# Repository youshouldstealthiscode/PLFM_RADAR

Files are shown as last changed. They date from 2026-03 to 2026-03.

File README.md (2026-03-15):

# AERIS-10: Open Source Pulse Linear Frequency Modulated Phased Array Radar




)


AERIS-10 Radar System

AERIS-10 is an open-source, low-cost 10.5 GHz phased array radar system featuring Pulse Linear Frequency Modulated (LFM) modulation. Available in two versions (3km and 20km range), it's designed for researchers, drone developers, and serious SDR enthusiasts who want to explore and experiment with phased array radar technology.

AERIS-10 Radar System

## 📡 Overview

The AERIS-10 project aims to democratize radar technology by providing a fully open-source, modular, and hackable radar system. Whether you're a university researcher, a drone startup, or an advanced maker, AERIS-10 offers a platform for experimenting with beamforming, pulse compression, Doppler processing, and target tracking.

## 🔬 Key Features

- **Open Source Hardware & Software** - Complete schematics, PCB layouts, firmware, and software available
- **Dual Version Availability**:
  - **AERIS-10N (Nexus)**: 3km range with 8x16 patch antenna array
  - **AERIS-10E (Extended)**: 20km range with 32x16 dielectric-filled slotted waveguide array
- **Full Electronic Beam Steering** - ±45° electronic steering in elevation and azimuth
- **Advanced Signal Processing** - On-board FPGA handles pulse compression, Doppler FFT, MTI, and CFAR
- **Python GUI** - User-friendly interface with map integration
- **GPS/IMU Integration** - Real-time position and attitude correction
- **Modular Design** - Separate power management, frequency synthesis, and RF boards

## 🏗️ System Architecture

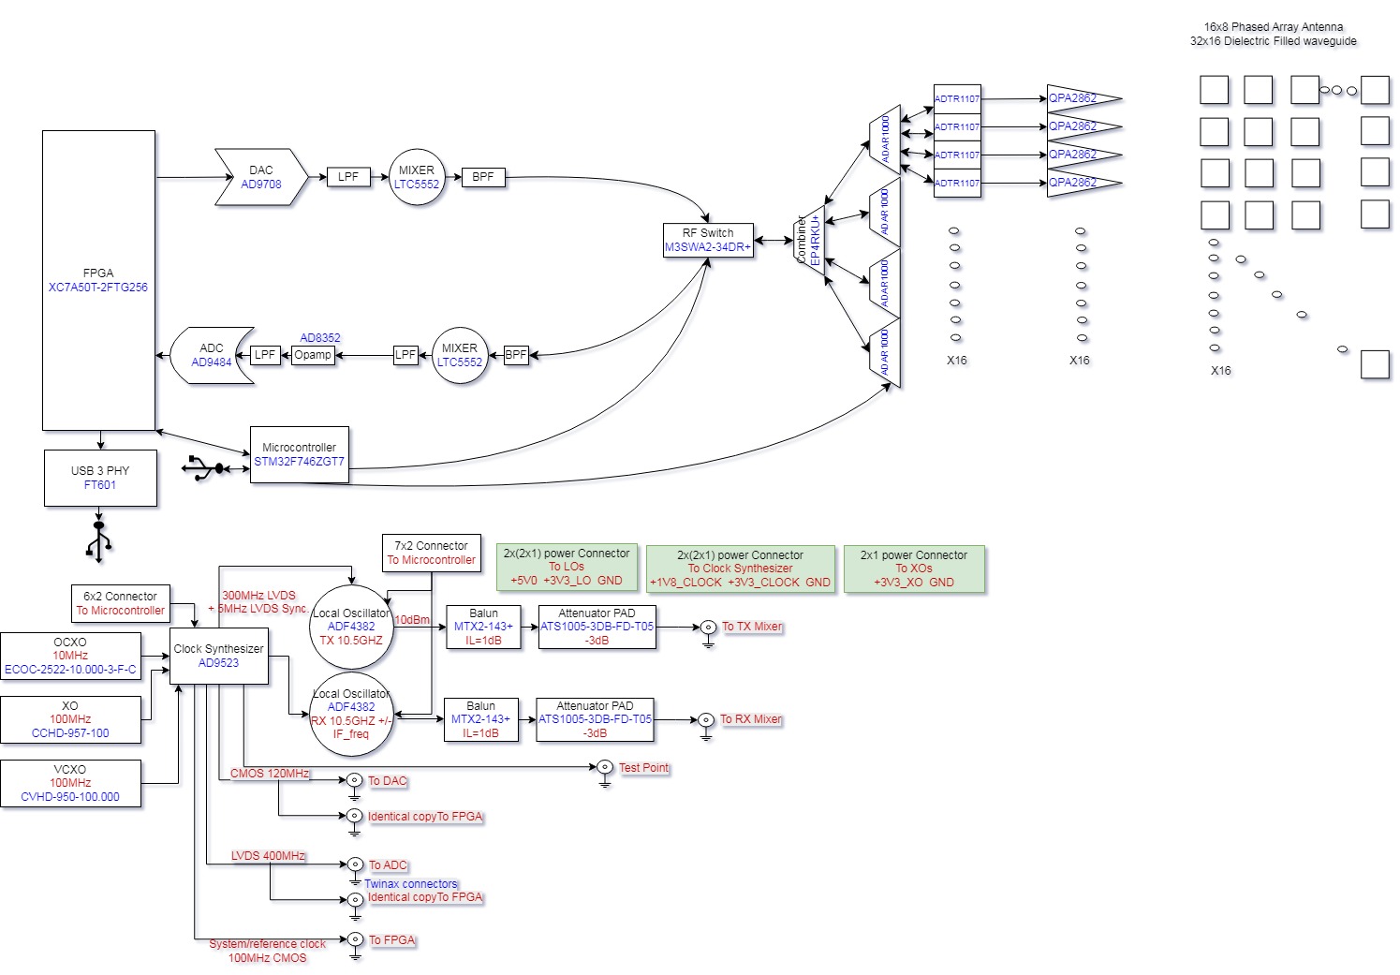
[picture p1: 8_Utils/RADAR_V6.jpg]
AERIS-10 Radar System


### Hardware Components

The AERIS-10 main sub-systems are:

- **Power Management Board** - Supplies all necessary voltage levels to the electronics components with proper filtering and sequencing (sequencing ensured by the microcontroller)

- **Frequency Synthesizer Board** - Uses a high-performance Low Jitter Clock Generator (AD9523-1) that supplies phase-aligned clock references for:
  - RX and TX Frequency Synthesizers (ADF4382)
  - DAC
  - ADC
  - FPGA

- **Main Board** containing:
  - **DAC** - Generates the RADAR Chirps
  - **2x Microwave Mixers (LT5552)** - For up-conversion and IF-down-conversion
  - **4x 4-Channel Phase Shifters (ADAR1000)** - For RX and TX chain beamforming
  - **16x Front End Chips (ADTR1107)** - Used for both Low Noise Amplifying (RX) and Power Amplifying (TX) stages
  - **XC7A100T FPGA** - Handles RADAR Signal Processing:
    - PLFM Chirps generation via the DAC
    - Raw ADC data read
    - Automatic Gain Control (AGC)
    - I/Q Baseband Down-Conversion
    - Decimation
    - Filtering
    - Forward FFT
    - Pulse Compression
    - Doppler, MTI and CFAR processing
    - USB Interface
  - **STM32F746xx Microcontroller** - Used for:
    - Power-up and power-down sequencing (see Power Management Excel File)
    - FPGA communication
    - Setup and Interface with:
      - Clock Generator (AD9523-1)
      - 2x Frequency Synthesizers (ADF4382)
      - 4x 4-Channel Phase Shifters (ADAR1000) for RADAR pulse sequencing
      - 2x ADS7830 ADCs (on Power Amplifier Boards) for Idq measurement
      - 2x DAC5578 (on Power Amplifier Boards) for Vg control
      - GPS module for GUI map centering
      - GY-85 IMU for pitch/roll correction of target coordinates
      - BMP180 Barometer
      - Stepper Motor
      - 8x ADS7830 Temperature Sensors for cooling fan control
      - RF switches

- **16x Power Amplifier Boards** - Used only for AERIS-10E version, featuring 10Watt QPA2962 GaN amplifier for extended range

- **Antenna Arrays**:
  - **AERIS-10N (Nexus)** - 8x16 patch antenna array
  - **AERIS-10X (Extended)** - 32x16 dielectric-filled slotted waveguide antenna array

- **Miscellaneous Components**:
  - Slip-Ring
  - Stepper Motor and drivers
  - Cooling Fans
  - Enclosure) 

### Processing Pipeline

1. **Waveform Generation** - DAC creates LFM chirps
2. **Up/Down Conversion** - LT5552 mixers handle frequency translation
3. **Beam Steering** - ADAR1000 phase shifters control 16 elements
4. **Signal Processing (FPGA)**:
   - Raw ADC data capture
   - I/Q baseband down-conversion
   - Decimation & filtering (CIC/FIR)
   - Pulse compression
   - Doppler FFT processing
   - MTI & CFAR detection
5. **System Management (STM32)**:
   - Power sequencing
   - Peripheral configuration
   - GPS/IMU integration
   - Stepper motor control
6. **Visualization (Python GUI)**:
   - Real-time target plotting
   - Map integration
   - Radar control interface

AERIS-10 Radar System

## 📊 Technical Specifications

| Parameter | AERIS-10N (Nexus) | AERIS-10X (Extended) |
|---|---|---|
| **Frequency** | 10.5 GHz | 10.5 GHz |
| **Max Range** | 3 km | 20 km |
| **Antenna** | 8x16 Patch Array | 32x16 Slotted Waveguide |
| **Beam Steering** | Electronic (±45°) | Electronic (±45°) |
| **Mechanical Scan** | 360° (stepper motor) | 360° (stepper motor) |
| **Output Power** | ~1Wx16 | 10Wx16 (GaN amplifier) |
| **Processing** | FPGA + STM32 | FPGA + STM32 |

## 🚀 Getting Started

### Prerequisites

- Basic understanding of radar principles
- Experience with PCB assembly (for hardware build)
- Python 3.8+ for the GUI software
- FPGA development tools (Vivado) for signal processing modifications

### Hardware Assembly

1. **Order PCBs**: All Gerber files are available in `/4_Schematics and Boards Layout`
2. **Source Components**: Bill of materials (BOM) in `/4_Schematics and Boards Layout/4_7_Production Files`
3. **Assembly**: Follow the assembly guide in `/10_docs/assembly_guide.md`
4. **Antenna**: Choose appropriate array for your version
5. **Enclosure**: 3D printable files in `/10_docs/Hardware/Enclosure`

## 📜 License

This project is open-source but uses **different licenses for hardware and software** to ensure proper legal coverage.

### Hardware Documentation
The hardware design files—including:
- Schematics and PCB layouts (in `/4_Schematics and Boards Layout`)
- Bill of Materials (BOM) files
- Gerber files and manufacturing outputs
- Mechanical drawings and enclosure designs

are licensed under the **CERN Open Hardware Licence Version 2 – Permissive (CERN-OHL-P)** .

This is a hardware-specific license that:
- ✅ Clearly defines "Hardware," "Documentation," and "Products"
- ✅ Includes explicit patent protection for contributors and users
- ✅ Provides stronger liability limitations (important for high-power RF)
- ✅ Aligns with professional open-hardware standards (CERN, OSHWA)

You may use, modify, and sell products based on these designs, provided you:
- Maintain the original copyright notices
- Distribute any modified designs under the same license
- Make your modifications available in Source format

### Software and Firmware
The software components—including:
- FPGA code (VHDL/Verilog in `/9_Firmware`)
- Microcontroller firmware (STM32)
- Python GUI and utilities

remain under the **MIT License** for maximum flexibility.

### Full License Texts
- The complete CERN-OHL-P license text is in the `LICENSE` file
- MIT license terms apply to software where not otherwise specified

### Why This Change?
Originally, the entire project used the MIT license. The community (special thanks to gmaynez!) pointed out that MIT lacks legal protections needed for physical hardware. The switch to CERN-OHL-P ensures the project is properly protected while maintaining the same permissive spirit.

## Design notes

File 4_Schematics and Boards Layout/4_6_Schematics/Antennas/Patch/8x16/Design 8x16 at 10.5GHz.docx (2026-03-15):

Design 8x16 at 10.5 GHz

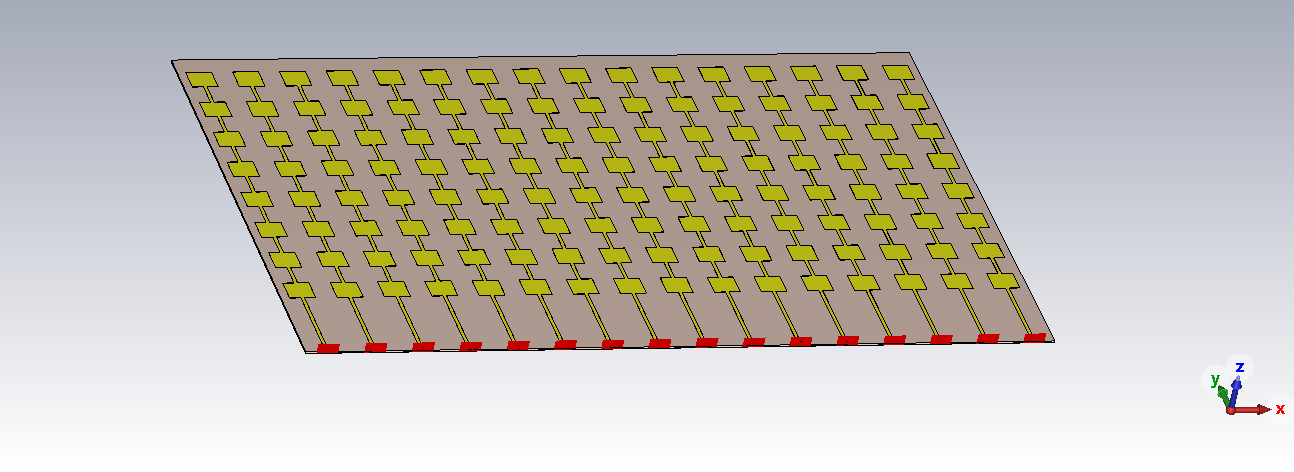
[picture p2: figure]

Working Frequency 10.5 GHz

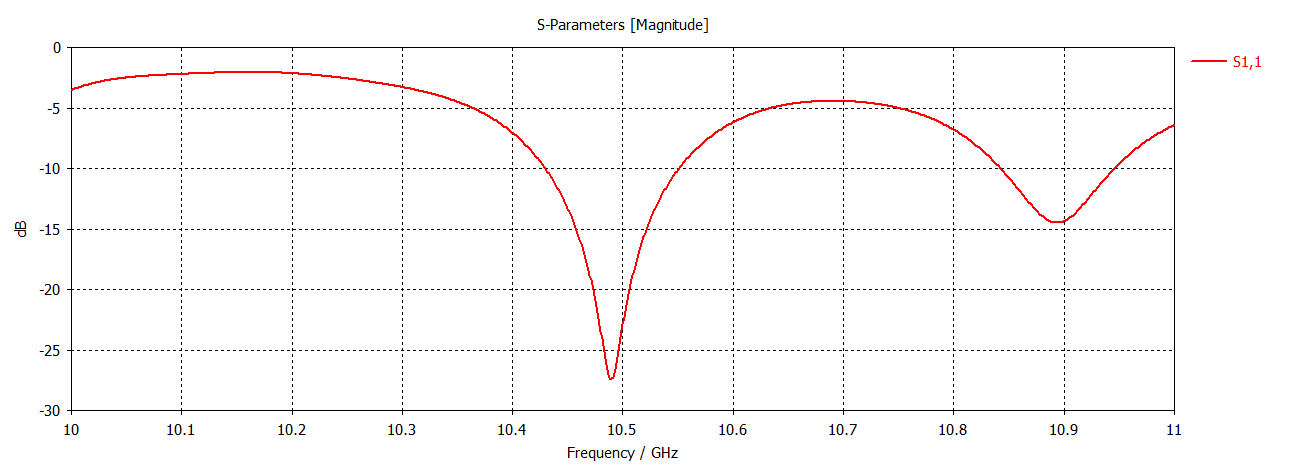
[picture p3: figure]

Gain 24.3 dBi

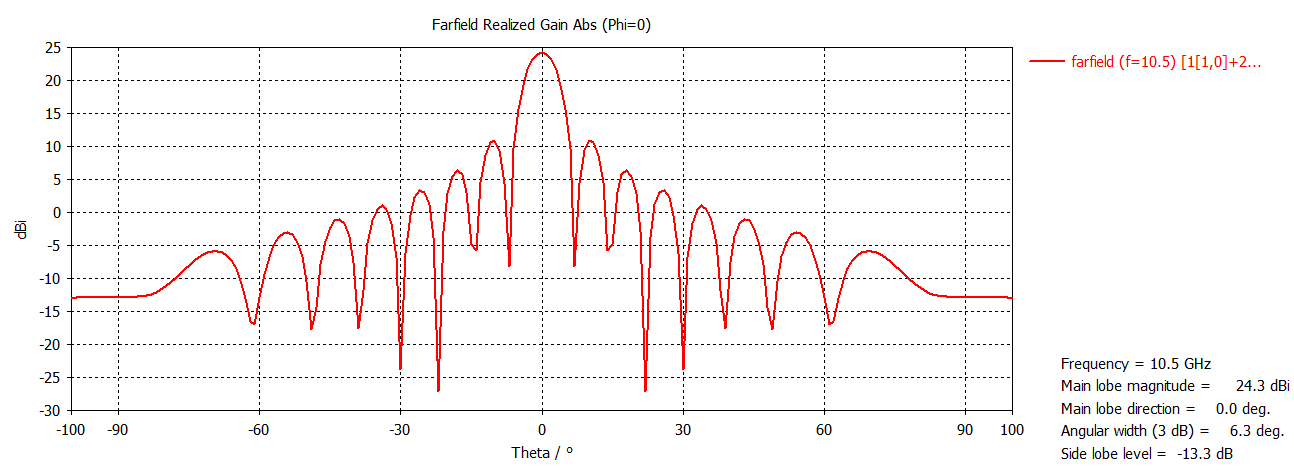
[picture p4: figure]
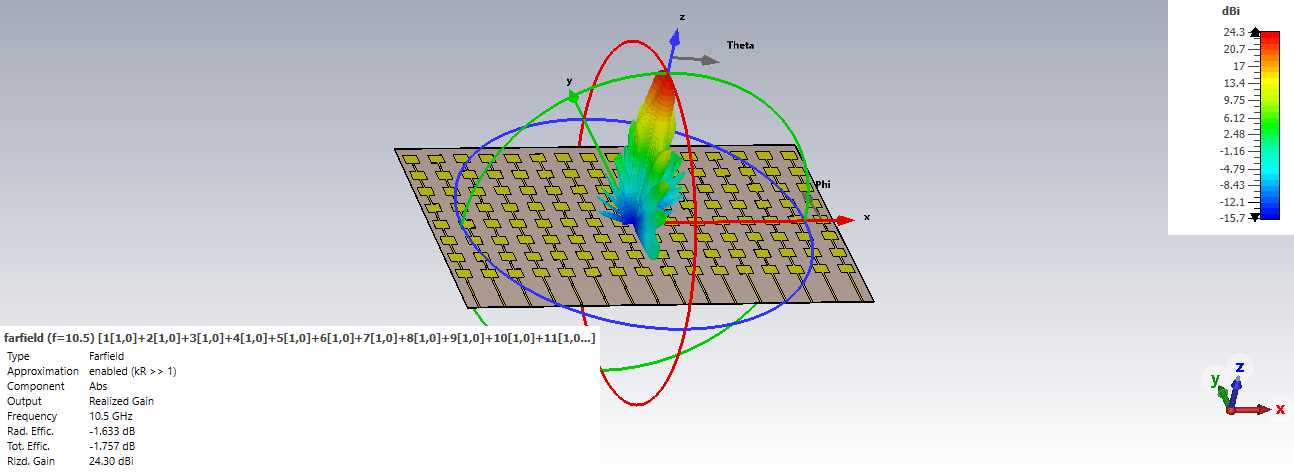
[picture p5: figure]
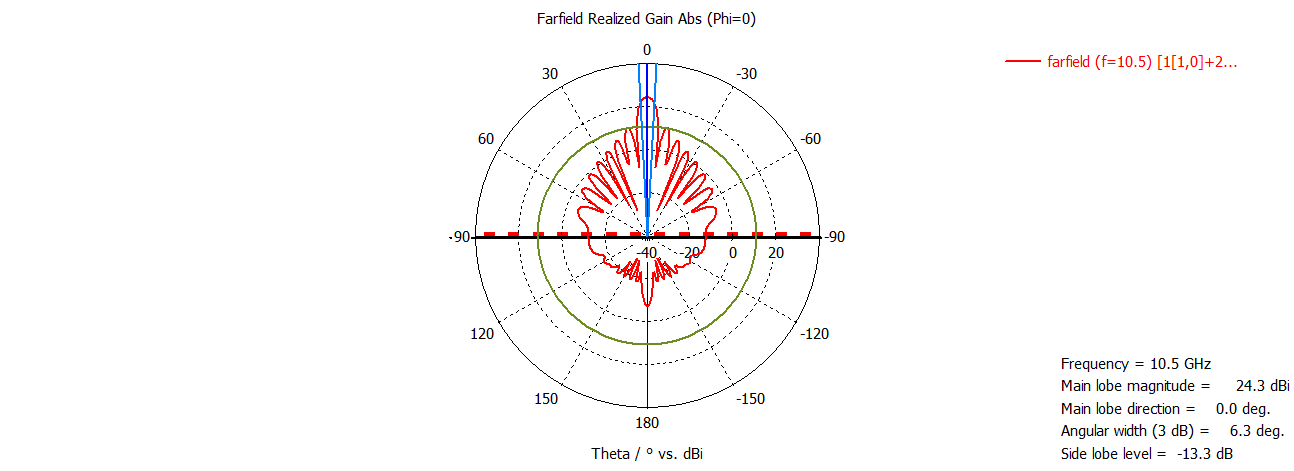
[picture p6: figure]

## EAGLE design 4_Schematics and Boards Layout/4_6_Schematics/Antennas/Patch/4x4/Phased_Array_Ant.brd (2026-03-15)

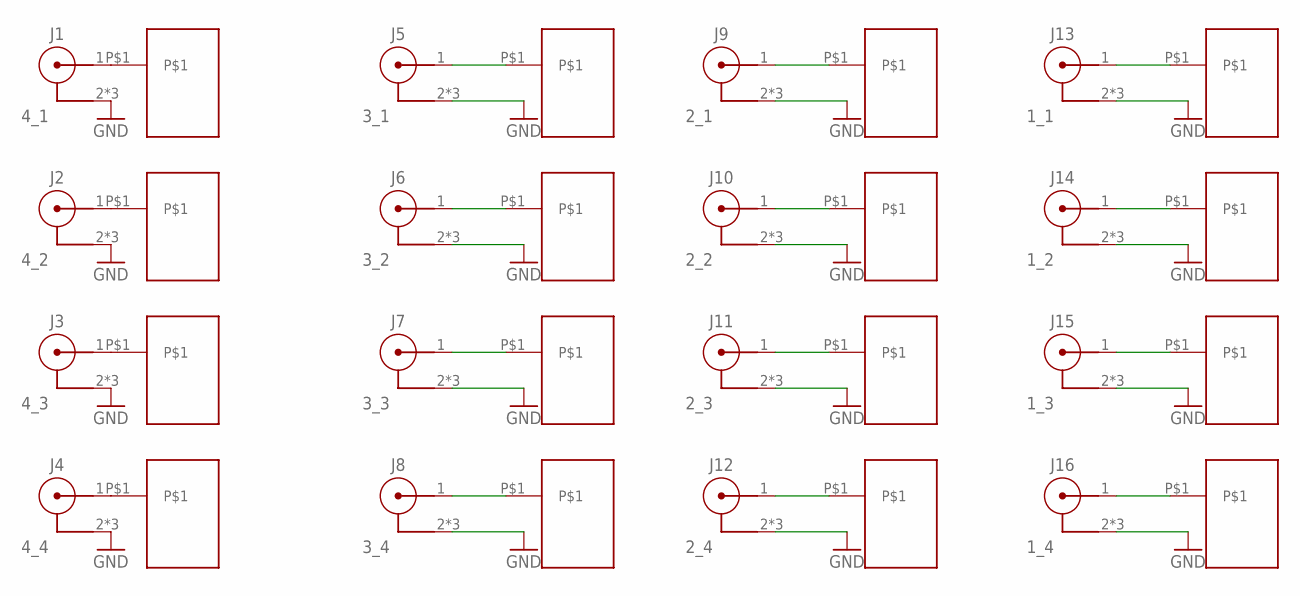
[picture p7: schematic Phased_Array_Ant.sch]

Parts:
J1: 4_1; 60124102122403
J2: 4_2; 60124102122403
J3: 4_3; 60124102122403
J4: 4_4; 60124102122403
J5: 3_1; 60124102122403
J6: 3_2; 60124102122403
J7: 3_3; 60124102122403
J8: 3_4; 60124102122403
J9: 2_1; 60124102122403
J10: 2_2; 60124102122403
J11: 2_3; 60124102122403
J12: 2_4; 60124102122403
J13: 1_1; 60124102122403
J14: 1_2; 60124102122403
J15: 1_3; 60124102122403
J16: 1_4; 60124102122403
U$1, U$2, U$3, U$4, U$5, U$6, U$7, U$8, U$9, U$10, U$11, U$12, U$13, U$14, U$15, U$16: 10.5GHZ_ANT

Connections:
GND: J1.2, J1.3 (2), J1.4 (2), J2.2, J2.3 (2), J2.4 (2), J3.2, J3.3 (2), J3.4 (2), J4.2, J4.3 (2), J4.4 (2), J5.2, J5.3 (2), J5.4 (2), J6.2, J6.3 (2), J6.4 (2), J7.2, J7.3 (2), J7.4 (2), J8.2, J8.3 (2), J8.4 (2), J9.2, J9.3 (2), J9.4 (2), J10.2, J10.3 (2), J10.4 (2), J11.2, J11.3 (2), J11.4 (2), J12.2, J12.3 (2), J12.4 (2), J13.2, J13.3 (2), J13.4 (2), J14.2, J14.3 (2), J14.4 (2), J15.2, J15.3 (2), J15.4 (2), J16.2, J16.3 (2), J16.4 (2)
unnamed: J1.1, U$1.P$1
unnamed: J2.1, U$2.P$1
unnamed: J3.1, U$3.P$1
unnamed: J4.1, U$4.P$1
unnamed: J5.1, U$5.P$1
unnamed: J6.1, U$6.P$1
unnamed: J7.1, U$7.P$1
unnamed: J8.1, U$8.P$1
unnamed: J9.1, U$9.P$1
unnamed: J10.1, U$10.P$1
unnamed: J11.1, U$11.P$1
unnamed: J12.1, U$12.P$1
unnamed: J13.1, U$13.P$1
unnamed: J14.1, U$14.P$1
unnamed: J15.1, U$15.P$1
unnamed: J16.1, U$16.P$1

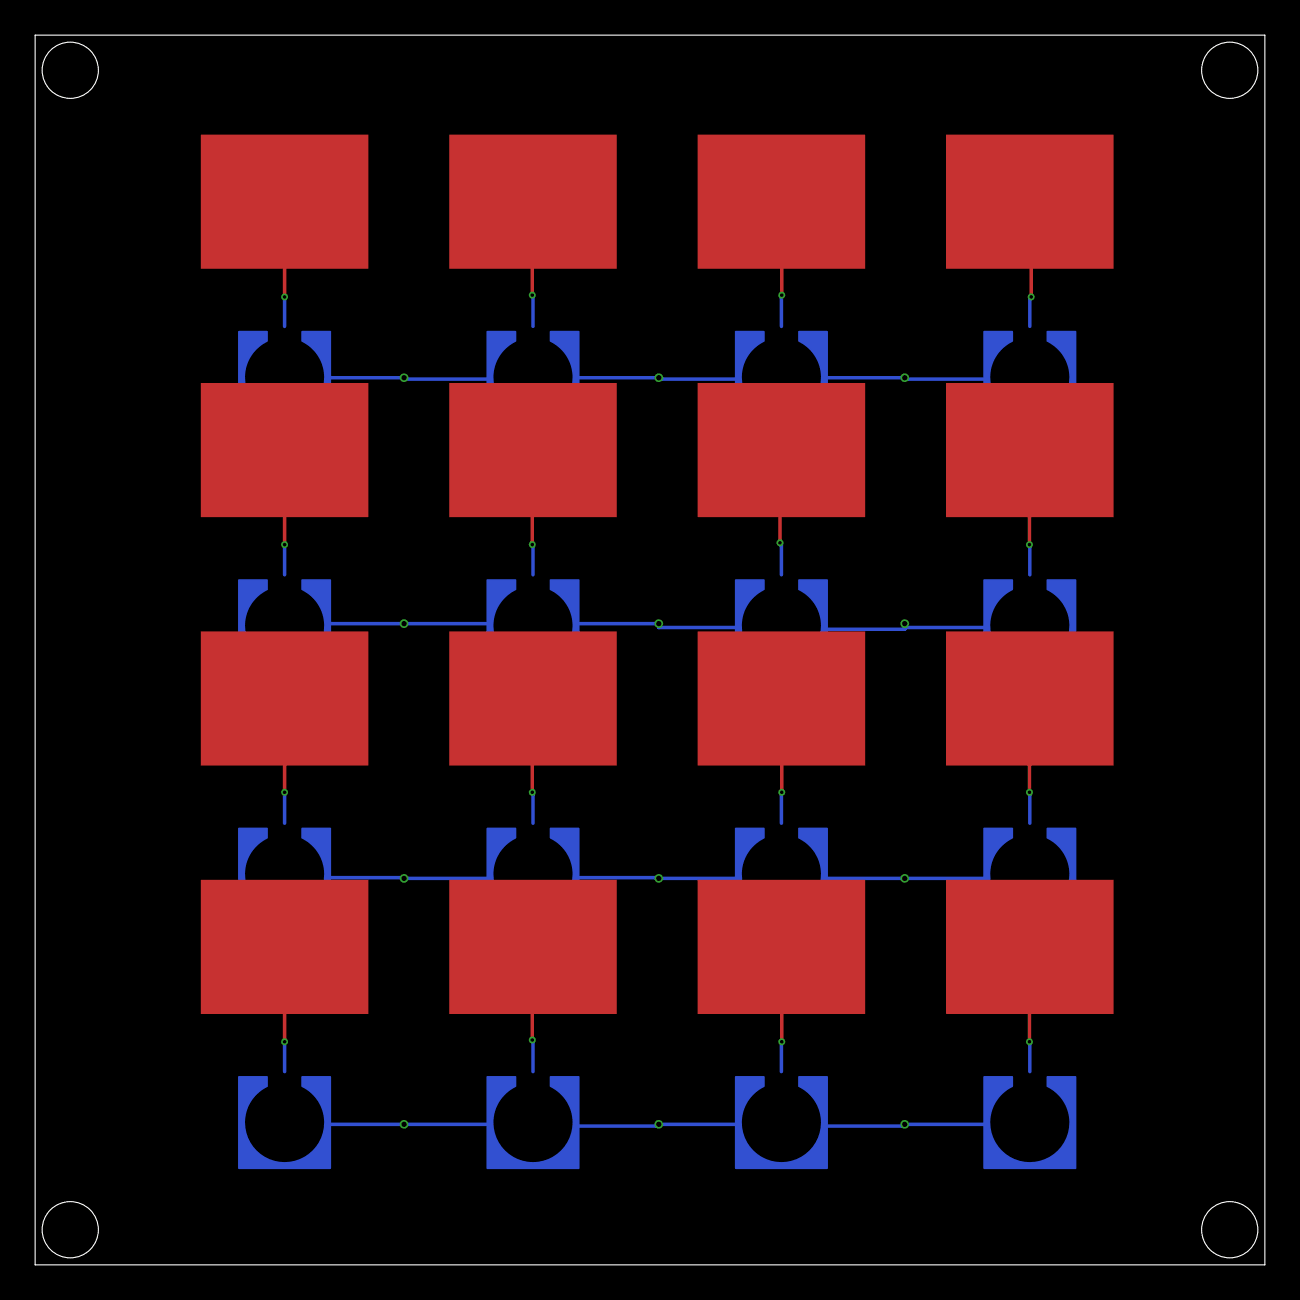
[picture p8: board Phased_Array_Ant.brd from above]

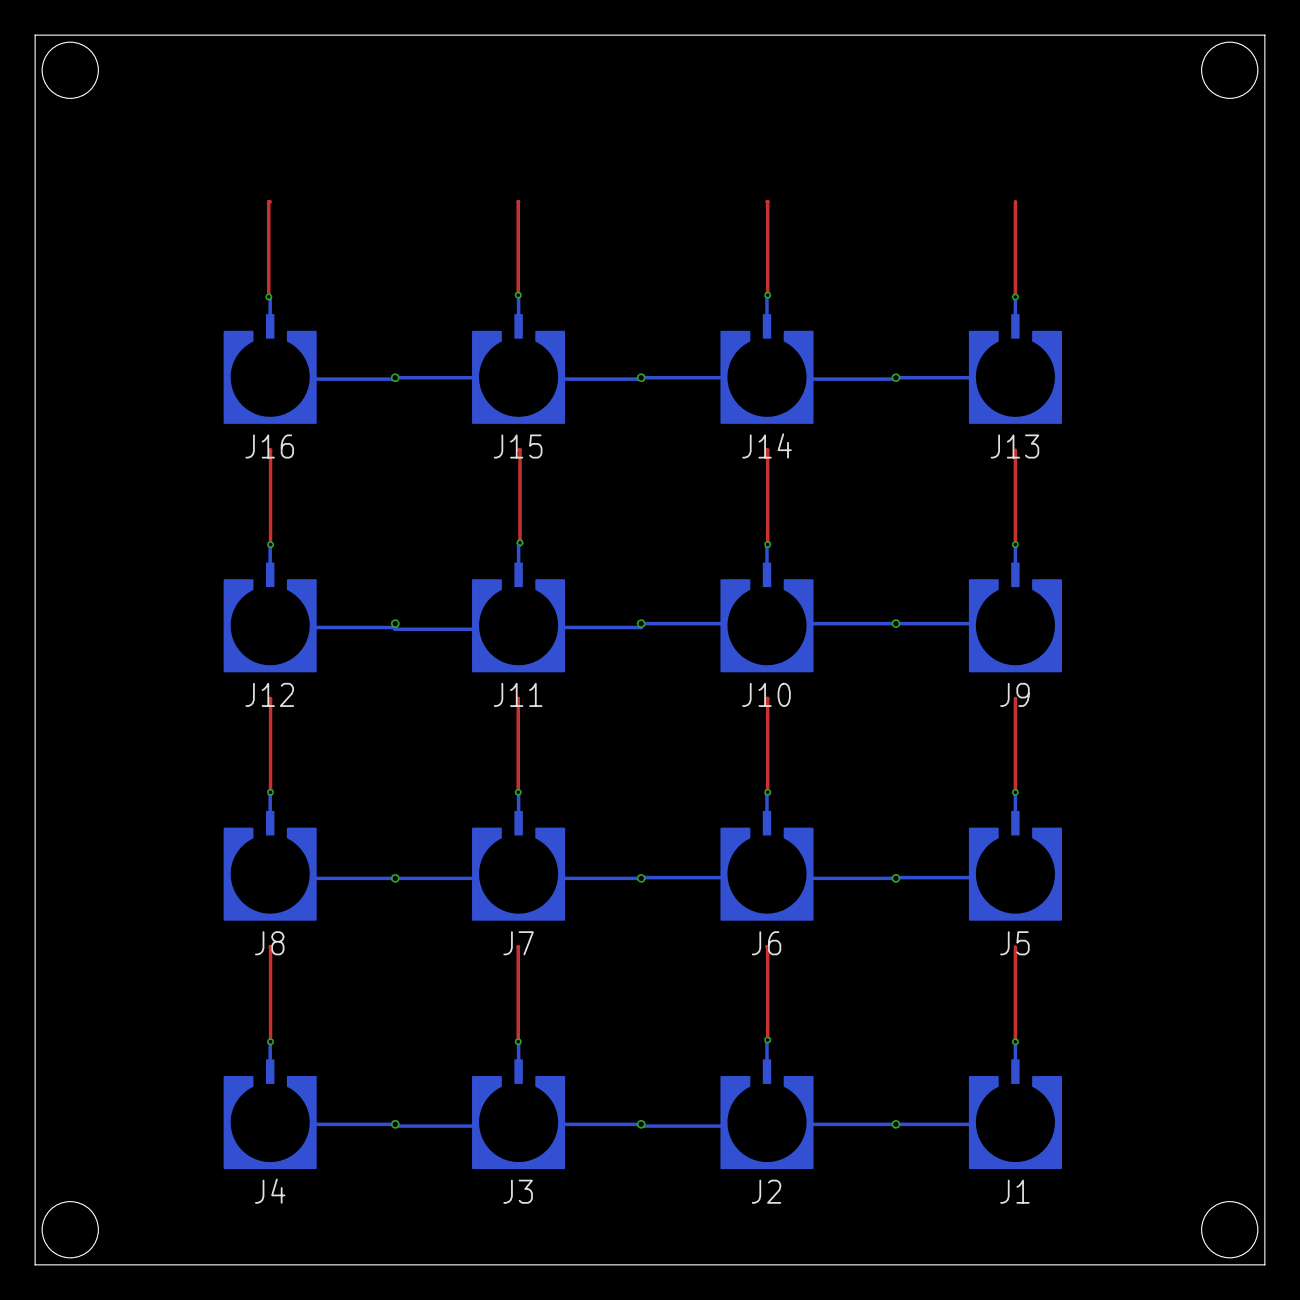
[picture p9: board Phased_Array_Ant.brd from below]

Board: 6 copper layers, 70.0 x 70.0 mm, 32 parts (16 on the bottom side), 17 nets.

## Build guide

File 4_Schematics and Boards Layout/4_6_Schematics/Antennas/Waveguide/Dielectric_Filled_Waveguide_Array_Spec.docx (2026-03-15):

# Dielectric-Filled Waveguide Phased Array Antenna — Specifications & Deliverables

Date: 2025-08-13 | Version: 1.0 | Prepared by: Nawfal MOTII

# Project Overview

High-power, dielectric-filled rectangular waveguide phased array antenna for X-band operation. The array comprises 16 parallel waveguide columns, each with 32 longitudinal slots (travelling wave architecture), separated at λ₀/2 to enable ±60° electronic steering across columns. High purity alumina (Al₂O₃, 99.5–99.8%) is used as the dielectric fill to reduce cross section while maintaining low loss and robust thermal performance.

# Key Specifications (Customer Inputs)

Operating Frequency (f₀) | 10.5 GHz
Array Topology | 16 columns × 32 slots/column (travelling‑wave, terminated)
Inter‑column Pitch (dᵧ) | λ₀/2 ≈ 14.28 mm at 10.5 GHz
Dielectric Material | High‑purity alumina (Al₂O₃, 99.5–99.8%)
Microwave Power | 15 W per column (total 240 W)
Feed Type | 16 SMA connectors (one per waveguide column)
Total Gain (broadside) | ≥ 31 dBi
Electronic Steering Range | ±60° (across waveguide columns)

# Derived / Recommended Specifications

Free‑space wavelength (λ₀) | 28.55 mm
Guide cross‑section (internal) | a = 8.5 mm, b = 3.5 mm (alumina‑filled)
TE₁₀ cutoff (f_c10) | 5.63 GHz
Higher-order cutoffs | TE₂₀ ≈ 11.27 GHz, TE₀₁ ≈ 13.68 GHz (both > 10.5 GHz)
Guide wavelength (λ_g) | 10.81 mm
Slot spacing (s = λ_g/2) | 5.40 mm
Starter slot length (L_s≈0.47λ_g) | 5.08 mm
Column length (32 slots incl. margins) | 0.173 m
Panel height (16 columns) | 0.223 m
Geometric aperture (A=L·H) | 0.0385 m²
Ideal directivity | 27.73 dBi
EIRP at 240 W, G=31 dBi | 54.8 dBW

# Electrical Performance Targets

- Return loss (S₁₁) per column: ≤ −12 dB at 10.5 GHz; ≤ −10 dB across 10.25–10.75 GHz.
- Gain (boresight): ≥ 31 dBi; design goal 31–32 dBi with Taylor −25 dB taper.
- Sidelobe level (broadside, both principal planes): ≤ −23 dB (goal ≤ −25 dB).
- Cross‑polarization: ≤ −20 dB within main beam (goal ≤ −25 dB).
- Scan performance across columns: continuous scan to ±60°; scan loss ≤ 2 dB at 60°.
- Polarization: Linear
- Input impedance per column: nominal 50 Ω at feed; probe placed ≈ λ_g/4 from short.
- Phase shifter resolution recommendation: ≤ 5.6° LSB (≈ 1° angle steps near boresight).

# Mechanical & Materials

- Waveguide body: aluminum or copper alloy split-block; internal a=8.5 mm, b=3.5 mm (dielectric-filled).
- Dielectric: high-purity alumina (Al₂O₃ 99.5–99.8%); full fill or partial sidewall slabs (per EM optimization).
- Connectors: 16× SMA female bulkhead (power rated at X band); one per column.
- Feed geometry: coax probe feed located ≈ λ_g/4 from shorted back wall, centered (or tuned offset) in y.
- Manufacturing tolerances: slot length ±0.05 mm; slot offset ±0.03 mm; slot center position ±0.05 mm; flatness per length ≤ 0.05 mm/100 mm.
- Surface finish: Ra ≤ 1.6 µm in the RF volume; deburr and radius sharp edges.
- Optional plating: silver or electroless nickel (ENIG) as agreed; document any thickness effects.
- Optional pressurization: dry air/N₂ up to 1–2 bar for breakdown margin (include seals if required).

# Thermal & Power

- Per column CW power: 15 W; total 240 W distributed across 16 columns.
- Continuous operation over ambient −20 °C to +60 °C (goal; to be confirmed).
- Internal temperature rise limited such that dielectric and adhesives remain within ratings (supplier datasheets).

# Interfaces & Control

- RF inputs: 16 SMA female bulkhead connectors, 50 Ω.
- Beam steering: progressive phase per column (external phase shifters on customer PCB).
- Reference coordinate system and connector numbering: as per final assembly drawing.

# Verification & Test (Acceptance Criteria)

- VNA measurements: S₁₁ per column and inter column over 9–12 GHz; provide plots and Touchstone (.sNp/.s2p) and CSV.
- Anechoic chamber: boresight gain and 2D patterns at 10.3/10.5/10.7 GHz; provide polar plots and CSV.
- Scan patterns: measured principal plane cuts at θ = 0°, ±30°, ±45°, ±60° with specified phase sets; CSV exports.
- Near field to far field transform acceptable if chamber size limits; include processing details.
- Power run: operate at 15 W/column CW for 30 minutes; verify no arcing, no detuning beyond specs.
- Dimensional inspection: slot length/offset/spacing, column pitch, connector positions per tolerances.

# Deliverables

- Final 3D CAD: STEP (.stp) and/or Parasolid (.x_t); panel assembly and split‑block parts.
- 2D manufacturing drawings (PDF + native CAD) with full dimensions and tolerances.
- DXF/DWG: slot patterns, connector hole locations, and any gasket/seal cutouts.
- Materials list / BOM: metals, dielectric (alumina), fasteners, plating, adhesives, gaskets, finishes.
- EM simulation package: project files (HFSS/CST), simulation settings, and parametric studies.
- Simulation results: • S‑parameters 9–12 GHz (plots + Touchstone + CSV) • Input impedance 9–12 GHz (plots + CSV) • Surface current distributions at 10.5 GHz (images + data) • Far‑field patterns at θ = 0°, ±30°, ±45°, ±60° (plots + CSV)
- Slot synthesis tables: per‑column slot centers, lengths, and offsets (CSV).
- Assembly instructions and tuning plan (if any trim adjustments are foreseen).
- Qualification / acceptance test report with measured data and comparison to targets.

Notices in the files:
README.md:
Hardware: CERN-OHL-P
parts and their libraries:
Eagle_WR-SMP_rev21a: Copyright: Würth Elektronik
